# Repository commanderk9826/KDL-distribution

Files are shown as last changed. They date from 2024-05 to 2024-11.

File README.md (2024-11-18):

# Introduction

KDL(Kust Data Logger)는 대학생 자작자동차대회 출전차량을 위해 제작한 데이터로깅 플랫폼입니다. 
가이드에 따라 실시간 원격 모니터링, 데이터 분석 도구 등을 쉽게 이용할 수 있습니다.<br>

참여자 : 이채훈, 옹미령, 강호, 이지규<br>
PCB제작 : 고민제<br>
최신버전 [ui_config.json](https://github.com/commanderk9826/KDL-distribution/blob/main/ui_configKUST.json)

**주요 기능**
- CAN, 3축 가속도, GPS, 디지털/아날로그 신호 등 다양한 데이터 기록
- Micro SD 카드에 로그 저장
- 실시간 텔레메트리(원격 데이터 모니터링)
- 자체 시계(RTC)를 통한 실제 시간 추적
- 웹 기반 데이터 시각화 및 분석 도구

>**[가이드 문서](https://github.com/commanderk9826/KDL-distribution/wiki)**
>
>데이터로거 , 텔레메트리 모니터, 데이터 분석도구로 구성되어있습니다.

## 1. 데이터로거(KDL)

차량에 장착되어 데이터를 수집하는 장비입니다. 기록할 수 있는 데이터의 종류는

- CAN 2.0(A/B) 버스 트래픽
- 2채널 디지털 입력 신호
- 2채널 아날로그 입력 신호
- 3축 ±4g 가속도 (ADXL345)
- GPS 위치 정보 (NEO-7M)
- 전원(LV) 전압 및 자체 CPU 온도
- RTC 실제 시간 정보

<br>각 기능에 대한 설명은 [KDL가이드](https://github.com/commanderk9826/KDL-distribution/wiki/KDL-가이드)를 참고합니다.



## 2. 텔레메트리 모니터

데이터로거가 통신하는 텔레메트리 서버와, 실시간 데이터 모니터링을 위한 웹 클라이언트입니다.

### 서버
따로 설정하지 않는 한 데이터로거는 기본적으로 [commanderk.site](http://commanderk.site) 를 사용하여 데이터를 실시간으로 전송합니다.

> 기본 제공되는 텔레메트리 서버는 확인된 사용자만 이용할 수 있습니다.
>
> 별도의 비용은 없으며, lch9826@gmail.com 로 팀 이름, 사용할 차량 ID와 key를 보내 주시면 사용자 등록이 완료됩니다.

서버를 개별적으로 구축하고 싶다면 [서버 구축 가이드](https://github.com/commanderk9826/KDL-distribution/wiki/서버-구축-가이드)와 [웹 활용 가이드](https://github.com/commanderk9826/KDL-distribution/wiki/웹-활용-가이드)를 참고하여 직접 self-hosting할 수 있습니다.

### 클라이언트
실시간 모니터링 웹 클라이언트는 [https://commanderk.site/live](https://commanderk.site/live) 에서 제공됩니다.

각 사용자가 개별적으로 UI를 설정할 수 있으며, UI 설정 파일을 내보내고 불러오는 기능을 지원합니다.

자세한 사용법은 [클라이언트 사용 가이드](https://github.com/commanderk9826/KDL-distribution/wiki/클라이언트-사용-가이드)를 참고합니다.





## 데이터분석도구

데이터로거는 데이터를 정해진 [로그 프로토콜](https://github.com/commanderk9826/KDL-distribution/wiki/로그-프로토콜)에 따라 바이너리 파일로 SD 카드에 기록합니다.

이러한 로그를 사람이 읽을 수 있도록 json 및 csv 파일로 변환하는 해석기와, 데이터를 그래프로 시각화하는 분석 도구 모음입니다.

모두 웹 어플리케이션으로 구현되어 [https://www.commanderk.site](https://www.commanderk.site) 에서 바로 사용할 수 있습니다.

자세한 사용법은 [데이터 분석 도구 가이드](https://github.com/commanderk9826/KDL-distribution/wiki/데이터-분석-도구-가이드)를 참고합니다.



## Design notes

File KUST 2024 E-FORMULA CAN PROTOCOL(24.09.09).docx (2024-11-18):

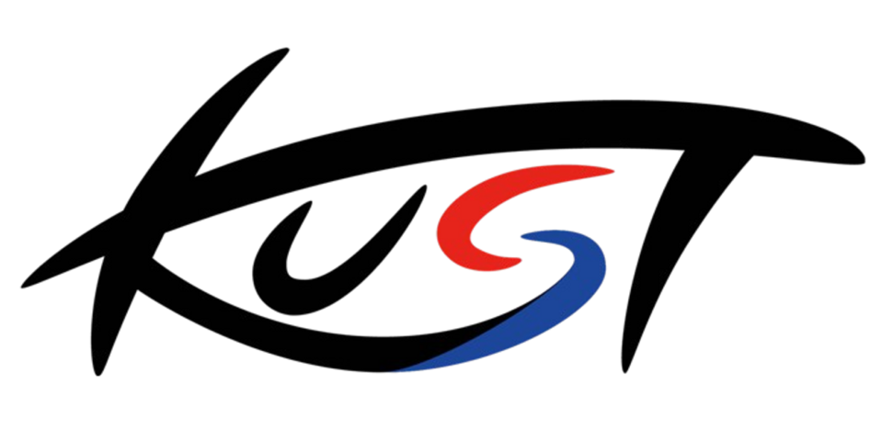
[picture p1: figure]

KUST 2024 E-FORMULA

CAN Protocol

1. System Diagram

CAN BUS

DL

SCU, LV BMS, PM100DX

SOC, JCU, HV BMS

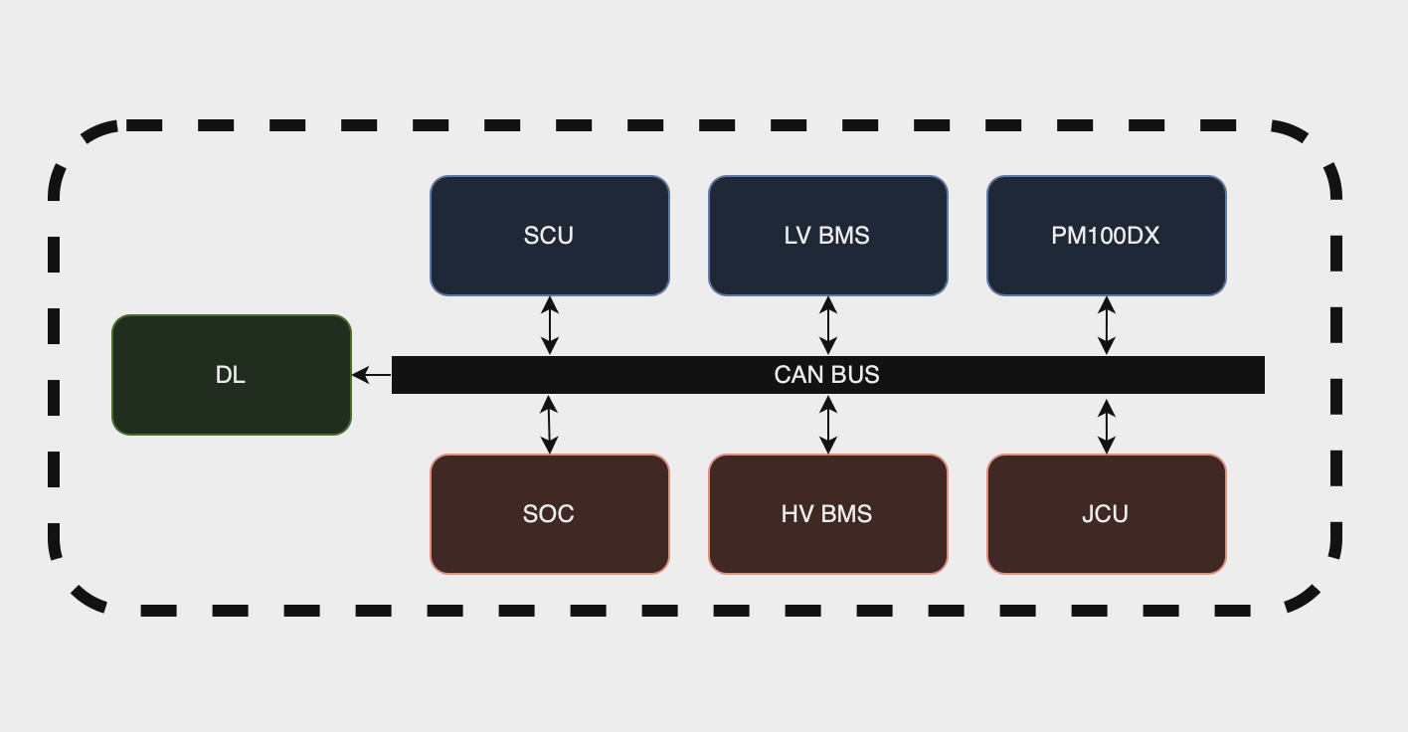
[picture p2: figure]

2. CAN Communication Parameters

CAN TYPE | CAN 2.0A(standard)
Bit Rate | 500kbit/sec
ID | 11bit
DLC | 8byte

3. CAN DATA MAP

Byte CAN-ID | 0 | | 1 | 2 | 3 | | | 4 | | 5 | 6 | 7

HV BMS
0x10 | SEG1[^1] VOLTAGE MAX | | | SEG1 VOLTAGE MIN | | | | SEG1[^2] TEMP MAX | | | SEG1 TEMP MIN
0x11 | SEG2 VOLTAGE MAX | | | SEG2 VOLTAGE MIN | | | | SEG2 TEMP MAX | | | SEG2 TEMP MIN
0x12 | SEG3 VOLTAGE MAX | | | SEG3 VOLTAGE MIN | | | | SEG3 TEMP MAX | | | SEG3 TEMP MIN
0x13 | SEG4 VOLTAGE MAX | | | SEG4 VOLTAGE MIN | | | | SEG4 TEMP MAX | | | SEG4 TEMP MIN
0x14 | SEG5 VOLTAGE MAX | | | SEG5 VOLTAGE MIN | | | | SEG5 TEMP MAX | | | SEG5 TEMP MIN
0x15 | PACK VOLTAGE[^3] | | | SEG1 VOTAGE | | SEG2 VOTAGE | | SEG3 VOTAGE | SEG4 VOTAGE | | SEG5 VOTAGE | | BMS STATE

JCU(Little Endian)
0x20 | AL | TSAL[^4] | | AIR1 SIG | | | AIR2 SIG | AIR1 PWR[^5] | PRE2 REL[^6] | | SDC V[^7] | | | | -
0x21 | PRE1 HV V | | | PRE1 MC V | | | | DIS MC V | | | - | | | | -

SOC
0x30 | PACK SOC[^8] | | | HV Sensor Current[^9] | | | | HV Power[^10] | | | Peak Current | ~~cnt~~

LV BMS
0x50 | Max Cell Voltage[^11] | | | Min Cell Voltage | | | | Pack Voltage | | | Stack Voltage
0x51 | ~~Pack~~ ~~Current~~~~[^12]~~ | | | CELL Temp[^13] | | | | FET Temp | | | CONV Temp
0x52 | hi2c1.ErrorCode | | FET Status | Safety Status A | Safety Status B | | | Safety Status C | | PF Status A | PF Status B | PF Status C

SCU(Little Endian)
0x60 | FR Linear[^14] | | | FL Linear | | | | RR Linear | | | RL Linear
0x61 | FR Wheel Speed | | | FL Wheel Speed | | | | RR Wheel Speed | | | RL Wheel Speed
0x62 | Steer Linear[^15] | | | Brake Pressure1[^16] | | | | Brake Pressure2 | | | - | | | -

PM100DX(Little Endian)
0xA0 | Module A Temp[^17] | | | Module B Temp | | | | Module C Temp | | | Gate Driver Board Temp
0xA1 | Control board Temp | | | ~~R~~~~TD#1 Temp~~ | | | | ~~R~~~~TD#2 Temp~~ | | | ~~R~~~~TD#3 Temp~~
0xA2 | ~~C~~~~oolant Temp~~ | | | ~~H~~~~ot Spot Temp~~ | | | | Motor Temp | | | ~~T~~~~orque Shudder~~
~~0~~~~xA4~~ | ~~F~~~~orward switch~~ | | ~~R~~~~everse switch~~ | ~~B~~~~rake switch~~ | ~~R~~~~EGEN Disable Switch~~ | | | ~~I~~~~gnition switch~~ | | ~~S~~~~tart switch~~ | ~~V~~~~alet Mode~~ | ~~S~~~~tatus of Digital Input~~
0xA5 | ~~M~~~~otor Angle~~ | | | Motor Speed[^18] | | | | ~~E~~~~lectrical Output Frequency~~ | | | ~~D~~~~elta Resolver Filtered~~
0xA6 | Phase A current | | | Phase B current | | | | Phase C current | | | DC Bus Current
0xA7 | DC Bus Voltage[^19] | | | Output Voltage | | | | ~~V~~~~AB~~ ~~Vd~~ ~~Voltage~~ | | | ~~V~~~~BC~~ ~~Vd~~ ~~Voltage~~
0xA8 | ~~F~~~~lux command~~ | | | ~~F~~~~lux feedback~~ | | | | Id feedback | | | Iq feedback
0xA9 | ~~1~~~~.5V Reference voltage~~ | | | ~~2.5V Reference voltage~~ | | | | ~~5V Reference voltage~~ | | | ~~12V Reference voltage~~
0xAA | VSM State | | ~~P~~~~W~~~~M~~ ~~Frequency~~ | Inverter State | Relay State | | | ~~1.~~ ~~I~~~~nverter Run~~ ~~mode(~~~~Bit 0)~~ ~~2.~~ ~~I~~~~nverter Active Discharge State~~ ~~(Bits 5-7)~~ | | ~~1.~~ ~~I~~~~nverter Command Mode(5-Bit0)~~ ~~2.~~ ~~R~~~~olling Counter Value~~ ~~(5-Bit4 thru 5-Bit7)~~ | ~~1.~~ ~~I~~~~nverter Enable~~ ~~State(~~~~Bit0)~~ ~~2.~~ ~~S~~~~tart Mode~~ ~~Active(~~~~Bit6)~~ ~~3.~~ ~~I~~~~nverter Enable~~ ~~Lockout(~~~~Bit7)~~ | ~~1.~~ ~~D~~~~irection~~ ~~Command(~~~~Bit 0)~~ ~~2.~~ ~~B~~~~MS Active~~ ~~(Bit 1)~~ ~~3.~~ ~~B~~~~MS Limiting~~ ~~Torque(~~~~Bit 2)~~ ~~4.~~ ~~L~~~~imit Max~~ ~~Speed(~~~~Bit 3)~~ ~~5.~~ ~~L~~~~imit Hot~~ ~~Spot(~~~~Bit 4)~~ ~~6.~~ ~~L~~~~ow Speed~~ ~~Limiting(~~~~Bit 5)~~ ~~7.~~ ~~C~~~~oolant Temperature~~ ~~Limiting(~~~~Bit 6)~~
0xAB | POST Fault Lo | | | POST Fault Hi | | | | Run Fault Lo | | | Run Fault Hi
0xAC | Command Torque | | | Feedback Torque[^20] | | | | Power on Timer
0xAD | Modulation Index | | | Flux Weakening Output | | | | Id command | | | Iq command

5. 수정사항

2024-07-10 : ~~빨간글씨~~~~(~~~~텔레메트리~~ ~~필요~~~~x~~~~)~~

2024-07-12 : PM100DX, SCU => default : Little Endian/배수, 단위, ~~빨간글씨~~ 추가

2024-07-15 : 영광TEST피드백 수정사항 반영 완료

2024-07-31 : 7번 각주 Highlight , 11번 각주 Highlight, 상원님 수정 상황 반영 완료, Pm100dx 0xB0, 0xC0, 0xC1, 0xC2삭제, 각주에 들어갈 내용(Unit, Scale)

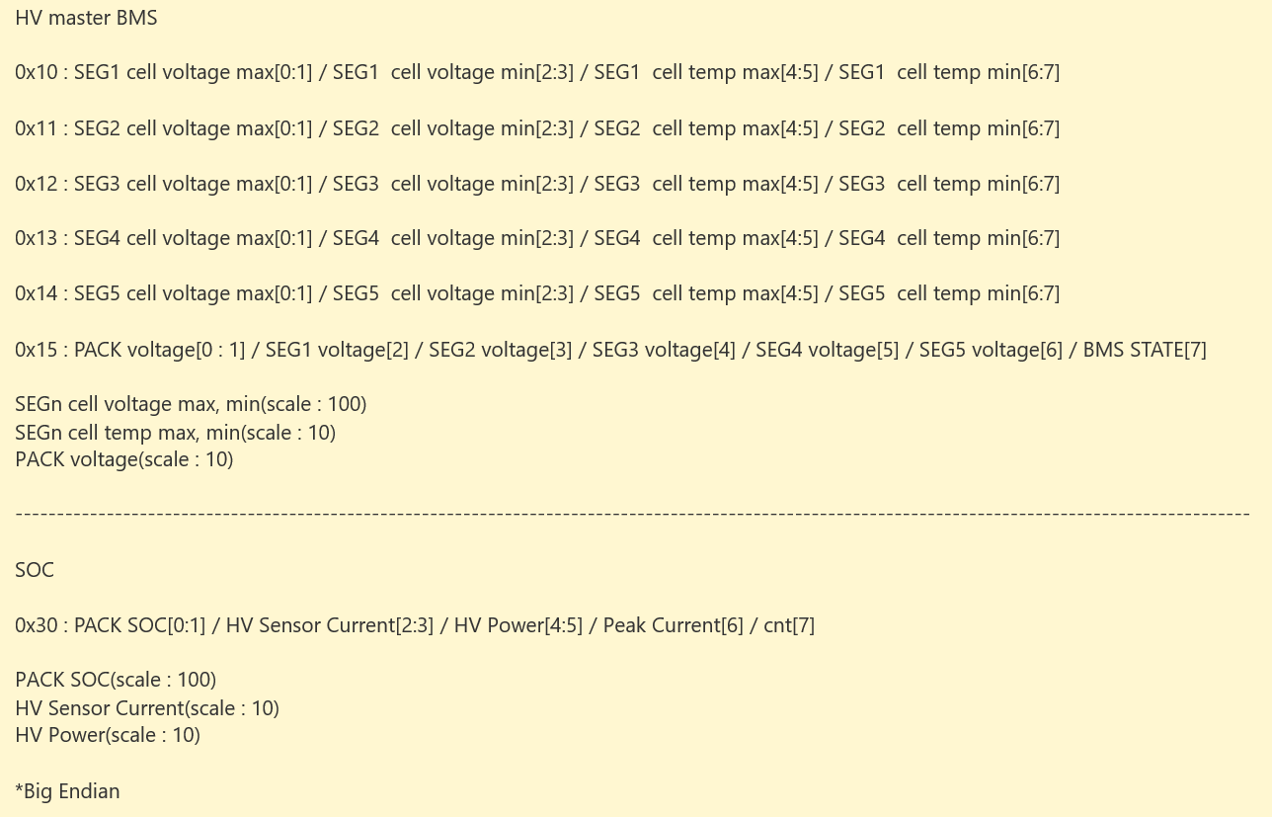
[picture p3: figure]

2024-08-10 : LV Charger 영구 삭제, 0x62 4~5 Break Pressure2 추가/HW Diagram 수정 및 재도식화(ccu x, braker temp x, gyro x)/JCU Protocol 수정

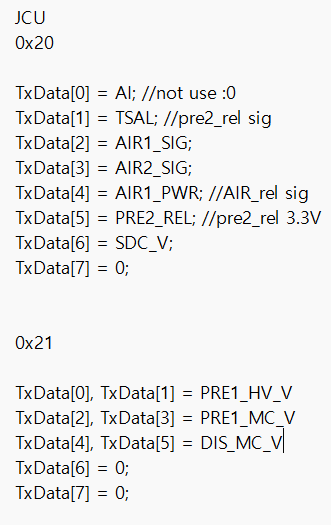
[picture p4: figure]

2024-08-12 : JCU => Little Endian, Brake Pressure => Unit, Scale 추가

2024-08-15 : Brake Pressure => 배율이 0.024가 아님. 하단 사진대로 브레이크 압력 센서 값을 계산하는데, 비선형 식이므로 SCU에서 아래의 식대로 계산해서 보내준 값을 받아야 함. VSM STAT도 BSPD 실험 시 봐야하는 중요한 값.

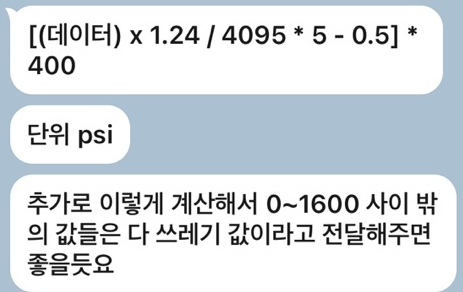
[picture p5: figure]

2024-08-30 : PM100dx => FeedBack Torque => Scale 0.1 추가, cnt 삭제

2024-09-09 : LV BMS 추가(Voltage, Current, Temp) => Little Endian

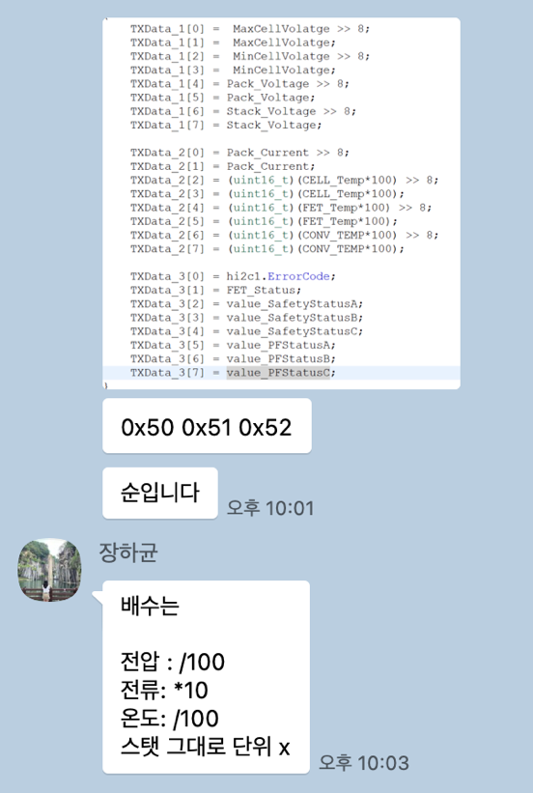
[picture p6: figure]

2024-09-27 : LV BMS => 배율 및 엔디안방식 조정

[^1] SEGn VOLTAGE MAX, MIN(Scale : 0.01)
[^2] SEGn TEMP MAX, MIN(Scale : 0.1)
[^3] PACK VOLTAGE(Scale : 0.1)
[^4] TSAL : PRE2 REL SIG
[^5] AIR1 PWR : AIR REL SIG
[^6] PRE2 REL : PRE2 REL 3.3V
[^7] SDC V, PRE1 HV V, PRE1 MC V, DIS MC V(Scale : 0.001, Unit : mV)
[^8] PACK SOC(Scale : 0.01)
[^9] HV Sensor Current(Scale : 0.1)
[^10] HV Power(Scale : 0.1)
[^11] Max Cell, Min Cell, Pack, Stack Voltage(Scale : 0.001)
[^12] Peak Current(Scale : 10)
[^13] CELL, FET, CONV Temp(Scale : 0.01)
[^14] FR, FL, RR, RL Linear(Scale : 0.01831)
[^15] Steer Linear(Scale : 0.036621)
[^16] Brake Pressure1, 2(Unit : psi)
[^17] Module n, Gate Driver Board, Control board, Motor Temp(Scale : 0.1)
[^18] Motor Speed(Unit : RPM)
[^19] DC Bus Voltage(Scale : 0.1)
[^20] Feedback Torque(Scale : 0.1)

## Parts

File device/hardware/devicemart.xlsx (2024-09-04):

상품번호 | 상품명 | 링크 | 패키지 | 라벨 | 제조사 | 단가 (단위:원) | BOM 수량 | 소계 (단위:원)
1295407 | MicroSDHC, Class4 32GB [SDSDQM-032G] | https://www.devicemart.co.kr/goods/view?no=1295407 |  |  | SanDisk | 5,500 | 1 | 5,500
27492 | ST-LINK/V2 | https://www.devicemart.co.kr/goods/view?no=27492 |  |  | STMicroelectronics | 45,000 | 1 | 45,000
190 | [5BG4UC00] 5파이 LED - 슈퍼고휘도 [투명/녹색] | https://www.devicemart.co.kr/goods/view?no=190 |  |  | DAKWANG (중국) | 300 | 1 | 300
191 | [5R3UC2-06] 5파이 LED - 슈퍼고휘도 [투명/빨강] | https://www.devicemart.co.kr/goods/view?no=191 |  |  | DAKWANG (중국) | 250 | 2 | 500
189 | [5BB4SC00] 5파이 LED - 슈퍼고휘도 [투명/파랑] | https://www.devicemart.co.kr/goods/view?no=189 |  |  | DAKWANG (중국) | 200 | 2 | 400
1132403 | [5Y3UC2-04] 5파이 LED - 슈퍼고휘도 [투명/노랑] | https://www.devicemart.co.kr/goods/view?no=1132403 |  |  | DAKWANG (중국) | 150 | 1 | 150
12400354 | [해외] SN65HVD1050DR | https://www.devicemart.co.kr/goods/view?no=12400354 | 8-SOIC (0.154", 3.90mm Width) |  | Texas Instruments | 2,340 | 1 | 2,340
1324925 | 아두이노 FT232RL USB to UART 컨버터 모듈 [SZH-CVBE-017] | https://www.devicemart.co.kr/goods/view?no=1324925 |  |  | SMG-A | 2,400 | 1 | 2,400
8854545 | [해외] CFS-0102MB | https://www.devicemart.co.kr/goods/view?no=8854545 |  |  | Nidec Copal Electronics | 1,940 | 1 | 1,940
15367591 | [해외] CDSOT23-T24 | https://www.devicemart.co.kr/goods/view?no=15367591 | TO-236-3, SC-59, SOT-23-3 |  | Bourns Inc. | 740 | 1 | 740
3938 | 5557용 클림프[5556T] | https://www.devicemart.co.kr/goods/view?no=3938 |  |  | MOLEX | 50 | 30 | 1,500
340 | 5557-12R(무색) | https://www.devicemart.co.kr/goods/view?no=340 |  |  | MOLEX | 300 | 1 | 300
368 | 5569-12A(무색) | https://www.devicemart.co.kr/goods/view?no=368 |  |  | MOLEX | 960 | 1 | 960
1384237 | [해외] SMA to uFL/u.FL/IPX/IPEX RF Adapter Cable [ad | https://www.devicemart.co.kr/goods/view?no=1384237 |  |  | Adafruit | 7,800 | 1 | 7,800
14870400 | GNSS/GPS 안테나 1M (외장/SMA/차량용) [SZH-GANT01] | https://www.devicemart.co.kr/goods/view?no=14870400 |  |  | SMG | 6,300 | 1 | 6,300
10895400 | NEO-7M 아두이노 GPS 수신모듈 [SZH-NT07] | https://www.devicemart.co.kr/goods/view?no=10895400 |  |  | SMG | 8,600 | 1 | 8,600
1279459 | ADXL345 가속도센서 모듈 [SZH-EK054] | https://www.devicemart.co.kr/goods/view?no=1279459 |  |  | OEM | 2,500 | 1 | 2,500
38518 | SMW200-02 | https://www.devicemart.co.kr/goods/view?no=38518 |  |  | YEONHO | 50 | 1 | 50
38519 | SMW200-03 | https://www.devicemart.co.kr/goods/view?no=38519 |  |  | YEONHO | 70 | 1 | 70
14843857 | [해외] SXH-001T-P0.6N | https://www.devicemart.co.kr/goods/view?no=14843857 |  |  | JST Sales America Inc. | 110 | 100 | 11,000
15164126 | [해외] B4B-XH-A | https://www.devicemart.co.kr/goods/view?no=15164126 |  |  | JST Sales America Inc. | 370 | 1 | 370
8187466 | [해외] CRCW12069K10FKEA | https://www.devicemart.co.kr/goods/view?no=8187466 | 1206 (3216 Metric) |  | Vishay Dale | 150 | 1 | 150
8218870 | [해외] CRCW12062K70JNEA | https://www.devicemart.co.kr/goods/view?no=8218870 | 1206 (3216 Metric) |  | Vishay Dale | 150 | 4 | 600
8246572 | [해외] CRCW12061K30FKEA | https://www.devicemart.co.kr/goods/view?no=8246572 | 1206 (3216 Metric) |  | Vishay Dale | 150 | 1 | 150
8241496 | [해외] CRCW12061K00FKEA | https://www.devicemart.co.kr/goods/view?no=8241496 | 1206 (3216 Metric) |  | Vishay Dale | 170 | 4 | 680
8246528 | [해외] CRCW1206100RFKEA | https://www.devicemart.co.kr/goods/view?no=8246528 | 1206 (3216 Metric) |  | Vishay Dale | 150 | 6 | 900
8246552 | [해외] CRCW1206470RFKEA | https://www.devicemart.co.kr/goods/view?no=8246552 | 1206 (3216 Metric) |  | Vishay Dale | 150 | 2 | 300
8225127 | [해외] CRCW1206910RFKEA | https://www.devicemart.co.kr/goods/view?no=8225127 | 1206 (3216 Metric) |  | Vishay Dale | 150 | 2 | 300
7585345 | [해외] 293D104X9035A2TE3 | https://www.devicemart.co.kr/goods/view?no=7585345 | 1206 (3216 Metric) |  | Vishay Sprague | 600 | 5 | 3,000
7589662 | [해외] 293D106X9016A2TE3 | https://www.devicemart.co.kr/goods/view?no=7589662 | 1206 (3216 Metric) |  | Vishay Sprague | 590 | 1 | 590
8246532 | [해외상품] CRCW1206120RFKEA | https://www.devicemart.co.kr/goods/view?no=8246532 | 1206 (3216 Metric) |  | Vishay Dale | 150 | 1 | 150

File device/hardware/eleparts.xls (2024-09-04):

프로젝트명 : 기본
프로젝트설명 : KDL v 2.0
No | 상품IMG | 상품명 | EPX | 상태 | 단량 | BOM | 단가 | 구매수량 | 상품가격 | 메모
1 |  | [Semtech] 2N3904 | EPX33GCB | 정상 | 2 |  | 37.27원 | 2 | 75원
2 |  | [CONNFLY Elec] FH01(2.54)-SS40P | EPX3333F | 정상 | 1 |  | 480원 | 1 | 480원
3 |  | [CONNFLY Elec] FH01(2.54)-DS80P | EPX33BXY | 정상 | 2 |  | 865.46원 | 2 | 1,731원
4 |  | [JINLING] PH01(2.54)-SS40P-11.5MM | EPX3333M | 정상 | 2 |  | 140원 | 2 | 280원
5 |  | [ShenzenAV] NodeMCU-32S Lua WiFi - ESP32 개발보드(USB-C) | EPY4YLBA | 정상 | 1 |  | 10,500원 | 1 | 10,500원
6 |  | [ABCO] CFR 1/4W 5% 120ohm | EPX34LPK | 정상 | 10 |  | 10원 | 10 | 100원
7 |  | [연호전자] YST200 | EPXVNMJ7 | 정상 | 50 |  | 10원 | 50 | 500원

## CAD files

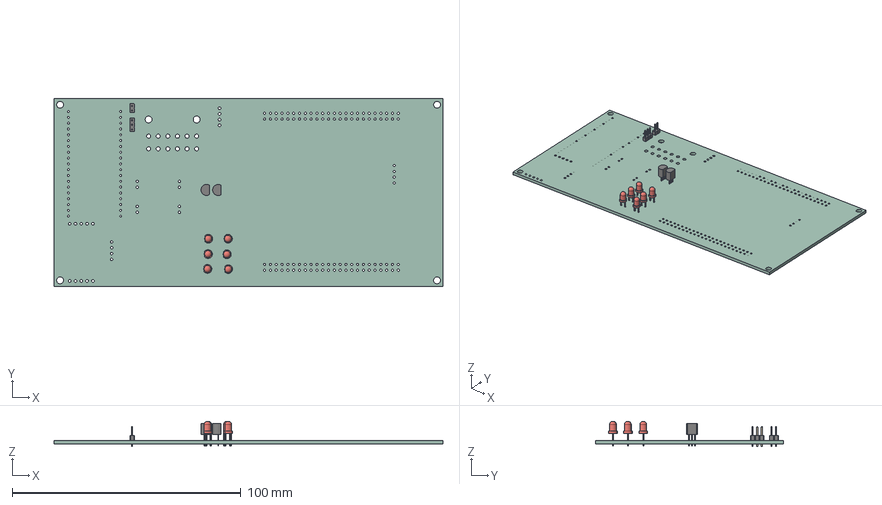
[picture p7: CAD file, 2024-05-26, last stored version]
device/hardware/KDL.step
170.0 x 82.0 x 11.1 mm
LED_D3.0mm x 6
PinHeader_1x03_P200mm_Vertical
TO-92_Inline_Narrow x 2
PinHeader_1x02_P200mm_Vertical
tma PCB

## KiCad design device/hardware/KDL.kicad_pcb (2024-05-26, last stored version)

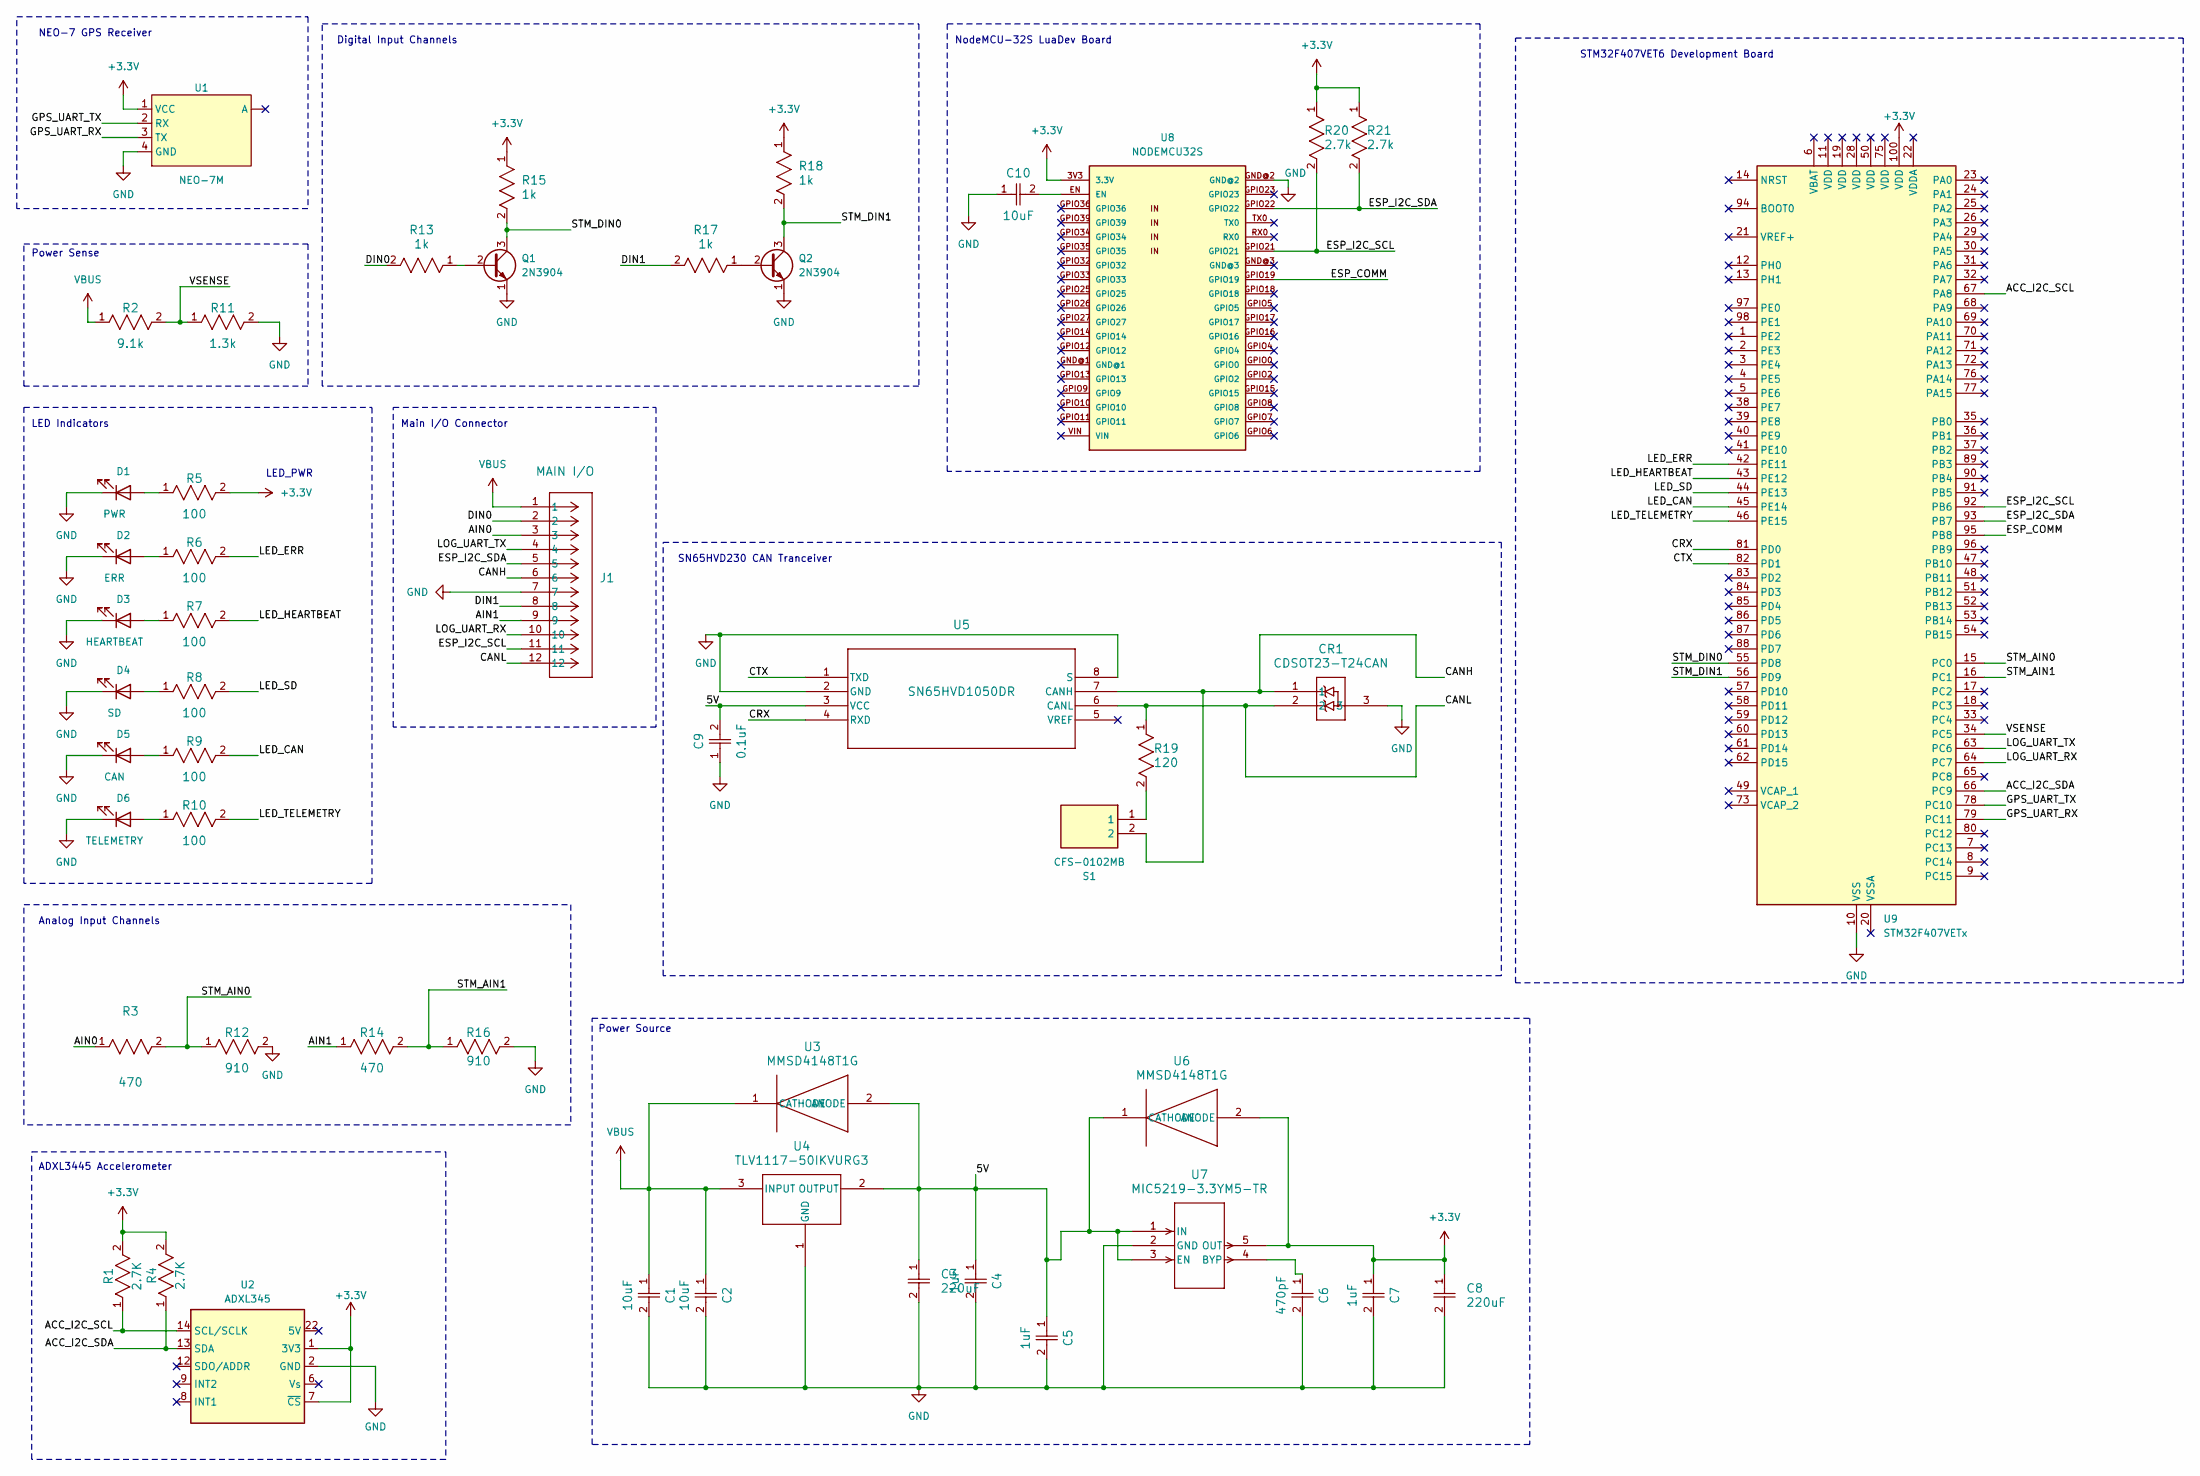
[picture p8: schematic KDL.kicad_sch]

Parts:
C1, C2, C10: 10uF; CAP_CL31_SAM
C3, C8: 220uF; CAP_ESK_E3_KEM
C4, C5, C7: 1uF; CAP_CL31_SAM
C6: 470pF; CAP_CL31_SAM
C9: 0.1uF; CAP_CL31_SAM
CR1: CDSOT23-T24CAN; SOT23-3L_STM
D1: PWR; LED_D3.0mm
D2: ERR; LED_D3.0mm
D3: HEARTBEAT; LED_D3.0mm
D4: SD; LED_D3.0mm
D5: CAN; LED_D3.0mm
D6: TELEMETRY; LED_D3.0mm
J1: MAIN I/O; CON_39301121
Q1, Q2: 2N3904; TO-92_Inline
R1, R4: 2.7K; RC1206N_YAG
R2: 9.1k; RC1206N_YAG
R3, R14: 470; RC1206N_YAG
R5, R6, R7, R8, R9, R10: 100; RC1206N_YAG
R11: 1.3k; RC1206N_YAG
R12, R16: 910; RC1206N_YAG
R13, R15, R17, R18: 1k; RC1206N_YAG
R19: 120; RC1206N_YAG
R20, R21: 2.7k; RC1206N_YAG
S1: CFS-0102MB; SOD10040X470N; Manufacturer_Part_Number CFS-0102MB
U1: NEO-7M; GPS_MODULE
U2: ADXL345; ADXL345_MODULE
U3, U6: MMSD4148T1G; SOD-123_ONS
U4: TLV1117-50IKVURG3; KVU3
U5: SN65HVD1050DR; D8
U7: MIC5219-3.3YM5-TR; SOT-23-5_M5_MCH
U8: NODEMCU32S
U9: STM32F407VETx; STM32F407_HOLDER

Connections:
+3.3V: C7.1, C8.1, R1.2, R4.2, R5.2, R15.1, R18.1, R20.1, R21.1, U1.1 (VCC), U2.1 (3V3), U2.7 (~CS), U6.2 (ANODE), U7.5 (OUT), U8.3V3 (3.3V), U9.100 (VDD)
/5V: C3.1, C4.1, C5.1, C9.2, U3.2 (ANODE), U4.2 (OUTPUT), U5.3 (VCC), U6.1 (CATHODE), U7.1 (IN), U7.3 (EN)
/ACC_I2C_SCL: R1.1, U2.14 (SCL/SCLK), U9.67 (PA8)
/ACC_I2C_SDA: R4.1, U2.13 (SDA), U9.66 (PC9)
/AIN0: J1.3, R3.1
/AIN1: J1.9, R14.1
/CANH: CR1.1, J1.6, S1.2, U5.7 (CANH)
/CANL: CR1.2, J1.12, R19.1, U5.6 (CANL)
/CRX: U5.4 (RXD), U9.81 (PD0)
/CTX: U5.1 (TXD), U9.82 (PD1)
/DIN0: J1.2, R13.2
/DIN1: J1.8, R17.2
/ESP_COMM: U8.GPIO19, U9.95 (PB8)
/ESP_I2C_SCL: J1.11, R20.2, U8.GPIO21, U9.92 (PB6)
/ESP_I2C_SDA: J1.5, R21.2, U8.GPIO22, U9.93 (PB7)
/GPS_UART_RX: U1.3 (TX), U9.79 (PC11)
/GPS_UART_TX: U1.2 (RX), U9.78 (PC10)
/LED_CAN: R9.2, U9.45 (PE14)
/LED_ERR: R6.2, U9.42 (PE11)
/LED_HEARTBEAT: R7.2, U9.43 (PE12)
/LED_SD: R8.2, U9.44 (PE13)
/LED_TELEMETRY: R10.2, U9.46 (PE15)
/LOG_UART_RX: J1.10, U9.64 (PC7)
/LOG_UART_TX: J1.4, U9.63 (PC6)
/STM_AIN0: R3.2, R12.1, U9.15 (PC0)
/STM_AIN1: R14.2, R16.1, U9.16 (PC1)
/STM_DIN0: Q1.3 (C), R15.2, U9.55 (PD8)
/STM_DIN1: Q2.3 (C), R18.2, U9.56 (PD9)
/VSENSE: R2.2, R11.1, U9.34 (PC5)
GND: C1.2, C2.2, C3.2, C4.2, C5.2, C6.2, C7.2, C8.2, C9.1, C10.1, CR1.3, D1.1 (K), D2.1 (K), D3.1 (K), D4.1 (K), D5.1 (K), D6.1 (K), J1.7, Q1.1 (E), Q2.1 (E), R11.2, R12.2, R16.2, U1.4 (GND), U2.2 (GND), U4.1 (GND), U5.2 (GND), U5.8 (S), U7.2 (GND), U8.GND@2, U9.10 (VSS), U9.27 (VSS), U9.74 (VSS), U9.99 (VSS)
unnamed: C10.2, U8.EN
unnamed: D1.2 (A), R5.1
unnamed: D2.2 (A), R6.1
unnamed: D3.2 (A), R7.1
unnamed: D4.2 (A), R8.1
unnamed: D5.2 (A), R9.1
unnamed: D6.2 (A), R10.1
unnamed: Q1.2 (B), R13.1
unnamed: Q2.2 (B), R17.1
unnamed: R19.2, S1.1
unnamed: C6.1, U7.4 (BYP)
VBUS: C1.1, C2.1, J1.1, R2.1, U3.1 (CATHODE), U4.3 (INPUT)

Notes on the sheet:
Power Source
Analog Input Channels
NodeMCU-32S LuaDev Board
LED_PWR
Main I/O Connector
ADXL3445 Accelerometer
NEO-7 GPS Receiver
Digital Input Channels
LED Indicators
STM32F407VET6 Development Board
Power Sense
SN65HVD230 CAN Tranceiver

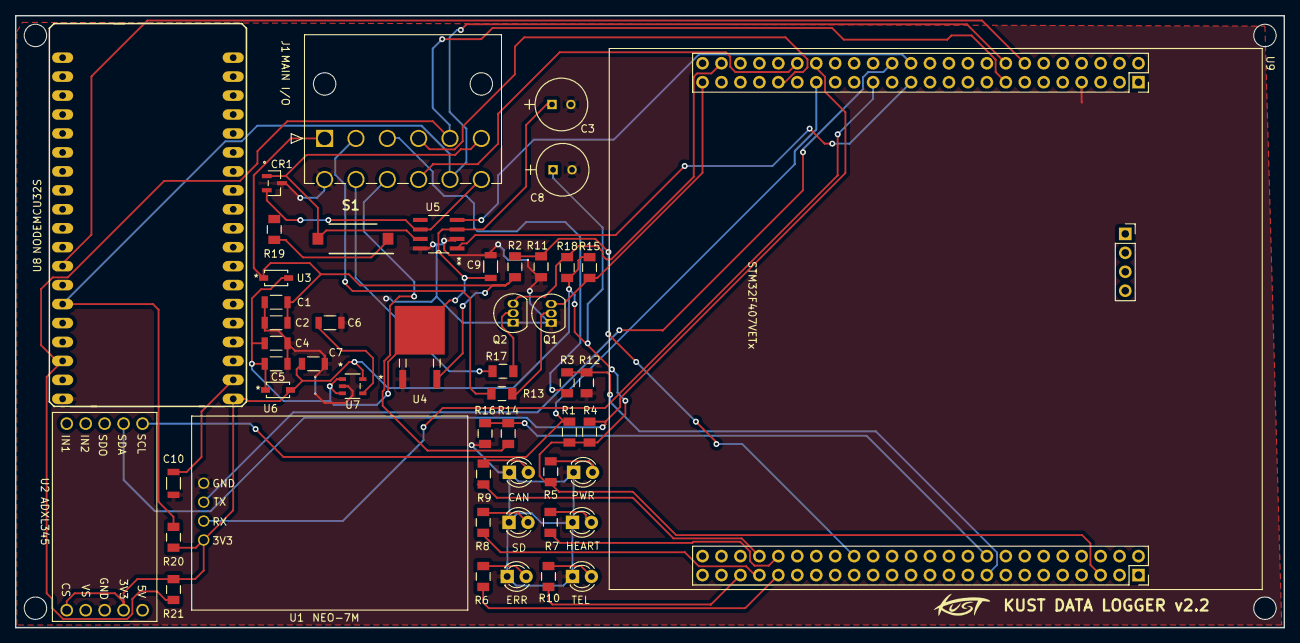
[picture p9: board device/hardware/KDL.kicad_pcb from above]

Board: 2 copper layers, 170.0 x 82.0 mm, 51 parts (0 on the bottom side), 42 nets.

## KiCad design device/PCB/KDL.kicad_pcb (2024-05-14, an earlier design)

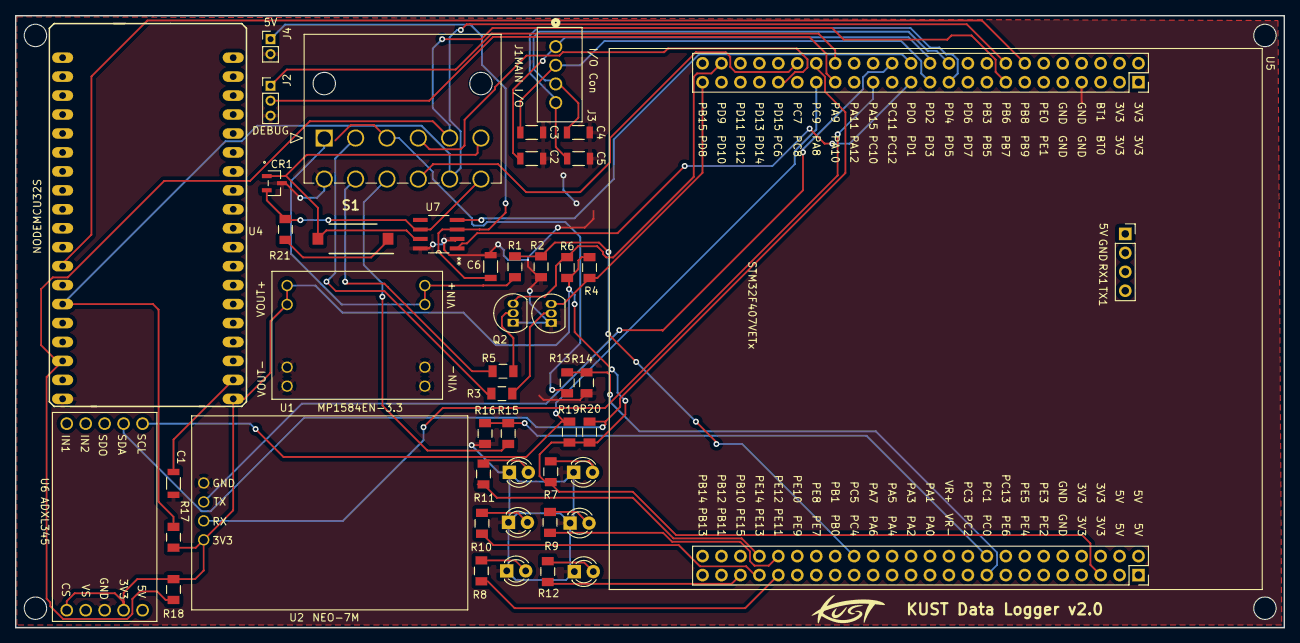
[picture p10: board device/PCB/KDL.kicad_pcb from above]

Board: 2 copper layers, 170.0 x 82.0 mm, 47 parts (0 on the bottom side), 47 nets.

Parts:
C1: 10uF; CAP_CL31_SAM
C2, C3, C4, C5: 1uF; CAP_CL31_SAM
C6: 0.1uF; CAP_CL31_SAM
CR1: CDSOT23-T24CAN; SOT23-3L_STM
D1: PWR; LED_D3.0mm
D2: ERR; LED_D3.0mm
D3: HEARTBEAT; LED_D3.0mm
D4: SD; LED_D3.0mm
D5: CAN; LED_D3.0mm
D6: TELEMETRY; LED_D3.0mm
J1: MAIN I/O; CON_39301121
J2: DEBUG; PinHeader_1x03_P2.00mm_Vertical
J3: I/O Con; CONN_B4B-XH-A_JST
J4: 5V; PinHeader_1x02_P2.00mm_Vertical
Q1, Q2: 2N3904; TO-92_Inline
R1: 9.1k; RC1206N_YAG
R2: 1.3k; RC1206N_YAG
R3, R4, R5, R6: 1k; RC1206N_YAG
R7, R8, R9, R10, R11, R12: 220; RC1206N_YAG
R13, R15: 470; RC1206N_YAG
R14, R16: 910; RC1206N_YAG
R17, R18: 2.7k; RC1206N_YAG
R19, R20: 2.7K; RC1206N_YAG
R21: 120k; RC1206N_YAG
S1: CFS-0102MB; SOD10040X470N
U1: MP1584EN-3.3; MP1584EN_MODULE
U2: NEO-7M; GPS_MODULE
U4: NODEMCU32S
U5: STM32F407VETx; STM32F407_HOLDER
U6: ADXL345; ADXL345_MODULE
U7: SN65HVD1050DR; D8

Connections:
+3.3V: R4.1, R6.1, R7.2, R17.1, R18.1, R19.2, R20.2, U1.3 (OUT), U2.1 (VCC), U4.3V3 (3.3V), U5.100 (VDD), U6.1 (3V3), U6.7 (~CS)
/5V: C6.2, J4.1, U7.3 (VCC)
/ACC_I2C_SCL: R19.1, U5.67 (PA8), U6.14 (SCL/SCLK)
/ACC_I2C_SDA: R20.1, U5.66 (PC9), U6.13 (SDA)
/AIN0: J1.3, R13.1
/AIN1: J1.9, R15.1
/CANH: CR1.1, J1.6, S1.2, U7.7 (CANH)
/CANL: CR1.2, J1.12, R21.1, U7.6 (CANL)
/CRX: U5.81 (PD0), U7.4 (RXD)
/CTX: U5.82 (PD1), U7.1 (TXD)
/DEBUG_UART_RX: J2.2, U5.69 (PA10)
/DEBUG_UART_TX: J2.1, U5.68 (PA9)
/DIN0: J1.2, R3.2
/DIN1: J1.8, R5.2
/ESP_COMM: U4.GPIO19, U5.95 (PB8)
/ESP_I2C_SCL: J1.11, R17.2, U4.GPIO21, U5.92 (PB6)
/ESP_I2C_SDA: J1.5, R18.2, U4.GPIO22, U5.93 (PB7)
/GPS_UART_RX: U2.3 (TX), U5.79 (PC11)
/GPS_UART_TX: U2.2 (RX), U5.78 (PC10)
/IO1: C2.2, J3.1, U5.83 (PD2)
/IO2: C3.2, J3.2, U5.84 (PD3)
/IO3: C4.2, J3.3, U5.85 (PD4)
/IO4: C5.2, J3.4, U5.86 (PD5)
/LED_CAN: R11.2, U5.45 (PE14)
/LED_ERR: R8.2, U5.42 (PE11)
/LED_HEARTBEAT: R9.2, U5.43 (PE12)
/LED_SD: R10.2, U5.44 (PE13)
/LED_TELEMETRY: R12.2, U5.46 (PE15)
/LOG_UART_RX: J1.10, U5.64 (PC7)
/LOG_UART_TX: J1.4, U5.63 (PC6)
/STM_AIN0: R13.2, R14.1, U5.15 (PC0)
/STM_AIN1: R15.2, R16.1, U5.16 (PC1)
/STM_DIN0: Q1.3 (C), R4.2, U5.55 (PD8)
/STM_DIN1: Q2.3 (C), R6.2, U5.56 (PD9)
/VSENSE: R1.2, R2.1, U5.34 (PC5)
GND: C1.1, C2.1, C3.1, C4.1, C5.1, C6.1, CR1.3, D1.1 (K), D2.1 (K), D3.1 (K), D4.1 (K), D5.1 (K), D6.1 (K), J1.7, J2.3, J4.2, Q1.1 (E), Q2.1 (E), R2.2, R14.2, R16.2, U1.2 (GND), U1.4 (GND), U2.4 (GND), U4.GND@2, U5.10 (VSS), U6.2 (GND), U7.2 (GND), U7.8 (S)
unnamed: C1.2, U4.EN
unnamed: D1.2 (A), R7.1
unnamed: D2.2 (A), R8.1
unnamed: D3.2 (A), R9.1
unnamed: D4.2 (A), R10.1
unnamed: D5.2 (A), R11.1
unnamed: D6.2 (A), R12.1
unnamed: Q1.2 (B), R3.1
unnamed: Q2.2 (B), R5.1
unnamed: R21.2, S1.1
VBUS: J1.1, R1.1, U1.1 (IN)

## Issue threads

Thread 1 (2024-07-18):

커스텀 보드를 위한 STM32 회로

luftaquila, 2024-07-18:
안녕하세요 🙂

오랜만에 모노리스에 이슈가 생겨 해결하려고 왔다가 우연히 레포를 발견했네요. 둘러보다 커스텀 PCB를 보고 이슈 하나 남겨봅니다.

원래는 손땜으로 기판 만드는 자작차 팀들이 만들기 쉽도록 그냥 모듈째 꽂는 설계를 했었는데요, 그러다 보니 PCB가 너무 커져서 상당히 큰 단점이 되는 것 같더라고요. 그래서 시간이 되면 아예 모듈 없이 전부 SMD 부품으로 설계해서 소형화를 해보려고 계획 중인데 시간이 많지 않네요.

비슷한 생각으로 SMD 부품들 올려서 PCB 설계하신걸 보고 인상깊어서 기왕 소형화하신 김에 모듈들도 보드에 올려버리셔도 될 것 같아서 참고 자료 남깁니다.

다만 STM32F407이나 ESP32의 USB 칩셋인 CP2102같은 건 손땜이 조금 어려울 텐데요, 사진상으로는 SMT를 치신 건지 손땜을 하신 건지 잘 안 보이네요.

* STM32 개발보드 회로도
    * https://stm32-base.org/assets/pdf/boards/original-schematic-STM32F407VET6-STM32_F4VE_V2.0.pdf
    * https://stm32-base.org/boards/STM32F407VET6-STM32-F4VE-V2.0.html
* ESP32 개발보드 회로도
    * https://wiki.geekworm.com/NodeMCU-32S

USB 단자로 Micro B 대신 C타입을 사용할 때 두 개의 CC핀에 붙여야 하는 5.1k 풀다운 저항만 유의하시면 될 듯합니다.
* https://forum.digikey.com/t/simple-way-to-use-usb-type-c-to-get-5v-at-up-to-3a-15w/7016

안전하게 작업하시고 대회에서 좋은 성적 거두시기를 기원합니다. 기회가 된다면 올해 대회장에서 한 번 뵈어요 :)

commanderk9826, 2024-08-01:
안녕하세요. 병준님, 저는 일전에 새벽에 팬이라고 자칭하면서 카톡했었던 국민대학교 재학중인 차량전장제어팀장 이채훈이라고 합니다. 저희는 일단 SMD저항 같은 경우 손납땜으로 진행하였습니다. 보내주신 자료는 이후에 내년 PCB설계시 요긴하게 사용할 수 있도록 하겠습니다. 정말 감사합니다.
현재 설계보고서 제출기간이라서, 다음주에 제가 테스트 진행하거나, 대회준비하면서 문제점 발생 및 해결 방법 공유할만한 내용이 있어서 전달드려도 될까요?? 저희 팀 인수인계용으로 몇개 정리해둔게 있어서, 혹시나 아주대 후배분들이 monolith를 더 업그레이드할 경우, 도움이 될 것 같아서 여쭤봅니다. 개인적으로는 오픈소스로 공유해주신게 너무 감사해서 어떤식으로 개조하고, 제작했는지 이후 어떤식으로 진행할 것인지도 공유해 드릴 수 있을 것 같습니다.

luftaquila, 2024-08-02:
안녕하세요 ㅎㅎ 반갑습니다. 손땜하셨다니 대단하시네요. 자료 공유는 언제든지 해주시면 감사하죠. 저희 학교가 아니어도 유용하게 사용할 팀들이 많을 것 같네요.

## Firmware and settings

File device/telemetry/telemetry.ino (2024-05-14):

#include <Wire.h>
#include <WiFi.h>
#include <RingBuf.h>
#include <ArduinoJson.h>
#include <SocketIOclient.h>

/****************************************************************************
 * Parameter Setting                                                        *
 ****************************************************************************/
#define NETWORK_SSID "<YOUR_HOTSPOT_ID>"
#define NETWORK_PASSWORD "<YOUR_HOTSPOT_PW>"
#define SERVER_NAME "<YOUR_SERVER_DOMAIN>"
#define CHANNEL_NAME "<YOUR_CHANNEL_NAME>"
#define CHANNEL_KEY "<YOUR_CHANNEL_KEY>"

/****************************************************************************
 * Hotspot AP configurations                                                *
 ****************************************************************************/
const char ssid[] = NETWORK_SSID;
const char pwd[]  = NETWORK_PASSWORD;

/****************************************************************************
 * telemetry server configuration                                           *
 ****************************************************************************/
const char server[] = SERVER_NAME;
const char url[] = "/socket.io/?EIO=4&device=1&channel="CHANNEL_NAME"&key="CHANNEL_KEY;
const int port = 80; // telemetry port of socket.io server

// GPIO and I2C configurations
#define ESP_COMM 19 // STM32 EXTI GPIO
#define I2C_SDA  22
#define I2C_SCL  21
#define I2C_ADDR (0x0) // generall call address
#define I2C_FREQ 400000 // 400kHz fast mode

// global flags
bool stm_handshake = false;
bool rtc_received = false;
bool server_conn = false;

// socket.io client
SocketIOclient socketIO;

// log buffer
RingBuf<char, 1024> tx_buf;
char log_payload[52] = "[\"tlog\",{\"log\":\"";

// server time
char rtc[19];

void setup() {
  Serial.begin(115200);
  Serial.printf("Wi-Fi:\n\tSSID: %s / PW: %s\nSERVER:\n\tname: %s:%d\n\turl: %s\nI2C:\n\tFREQ: %dHz / ADDR: 0x%02x / SDA: %d / SCL: %d\n", ssid, pwd, server, port, url, I2C_FREQ, I2C_ADDR, I2C_SDA, I2C_SCL);

  // init ESP_COMM
  pinMode(ESP_COMM, OUTPUT);
  digitalWrite(ESP_COMM, HIGH);

  // init I2C slave mode
  Wire.onReceive(i2c_rcv_callback);
  Wire.onRequest(i2c_req_callback);
  Wire.begin(I2C_ADDR, I2C_SDA, I2C_SCL, I2C_FREQ);

  // init Wi-Fi
  WiFi.disconnect();

  if (WiFi.getMode() & WIFI_AP) {
    WiFi.softAPdisconnect(true);
  }

  WiFi.begin(ssid, pwd);

  while (WiFi.status() != WL_CONNECTED) {
    delay(100);
  }

  WiFi.setAutoReconnect(true);
  WiFi.persistent(true);

  // attach socket
  socketIO.begin(server, port, url);
  socketIO.onEvent(socketIOEvent);

  disableCore0WDT();
}

void loop() {
  socketIO.loop();

  // server connection EXTI indicator
  if (stm_handshake && rtc_received) {
    if (WiFi.status() != WL_CONNECTED) {
      server_conn = false;
    }

    digitalWrite(ESP_COMM, server_conn ? HIGH : LOW);
  }

  // flush log buffer to server
  if (server_conn && !tx_buf.isEmpty()) {
    char pop;
    char buf[16];

    for (int x = 0; x < 16; x++) {
      tx_buf.lockedPop(pop);
      buf[x] = pop;
    }

    sprintf((log_payload + 16),
        "%02x%02x%02x%02x%02x%02x%02x%02x%02x%02x%02x%02x%02x%02x%02x%02x\"}]",
        buf[0], buf[1], buf[2], buf[3], buf[4], buf[5], buf[6], buf[7],
        buf[8], buf[9], buf[10], buf[11], buf[12], buf[13], buf[14], buf[15]);

    socketIO.sendEVENT(log_payload, 51);
  }
}

void socketIOEvent(socketIOmessageType_t type, uint8_t* payload, size_t length) {
  switch (type) {
    case sIOtype_CONNECT:
      server_conn = true;
      // join default namespace (no auto join in Socket.IO V3)
      socketIO.send(sIOtype_CONNECT, "/");
      break;

    case sIOtype_EVENT: {
      // parse server RTC time fix data
      StaticJsonDocument<64> json;
      DeserializationError jsonError = deserializeJson(json, payload, length);

      if (jsonError) {
        return;
      }

      const char *event = json[0];

      if (!rtc_received && (strcmp(event, "rtc_fix") == 0)) {
        strncpy(rtc, json[1]["datetime"], 19);
        Wire.slaveWrite((uint8_t *)rtc, 19);
        rtc_received = true;
      }
      break;
    }

    case sIOtype_DISCONNECT:
      server_conn = false;
      break;

    case sIOtype_ACK:
    case sIOtype_ERROR:
    case sIOtype_BINARY_EVENT:
    case sIOtype_BINARY_ACK:
    default:
      break;
  }
}

void i2c_rcv_callback(int len) {
  int i = 0;
  char buffer[16];

  while (Wire.available()) {
    if (i < 16) {
      buffer[i++] = Wire.read();
    } else {
      Wire.read(); // just flush buffers
    }
  }

  // STM32 handshake sequence
  if (!stm_handshake) {
    if (strncmp(buffer, "READY", 5) == 0) {
      stm_handshake = true;
      digitalWrite(ESP_COMM, LOW);
    }
  }

  // log received
  else if (i == 16) {
    for (int x = 0; x < 16; x++) {
      tx_buf.lockedPushOverwrite(buffer[x]);
    }
  }
}

void i2c_req_callback(void) {
  // nothing to do; write buffer is set at rtc_fix event
}

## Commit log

2024-05-14 add device
    [KDL-B_Cu.gbr, KDL-B_Mask.gbr, KDL-B_Paste.gbr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]
2024-05-26 add device ver2.2
    [KDL-B_Cu.gbr, KDL-B_Mask.gbr, KDL-B_Paste.gbr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]
2024-07-03 add ESP32
2024-07-04 add PCBguide
    [devicemart.xlsx, eleparts.xls]
